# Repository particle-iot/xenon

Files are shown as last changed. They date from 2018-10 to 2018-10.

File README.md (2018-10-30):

# Xenon

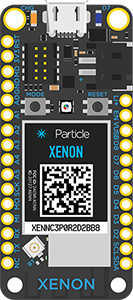
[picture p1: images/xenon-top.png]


### Overview

The Xenon is a low cost mesh-enabled development board that can act as either an endpoint or repeater within a Particle Mesh network.

The Xenon is mesh only and designed to function as the endpoint of your IoT network. It is based on the Nordic nRF52840 and has built-in battery charging circuitry so it’s easy to connect a Li-Po and deploy your local network in minutes.

The Xenon is best for connecting sensors, motors, pumps, valves, and points of data-interest. Pair it with an Argon or Boron gateway to get all that great data into the Device Cloud.

### Features

* Nordic Semiconductor nRF52840 SoC 
  * ARM Cortex-M4F 32-bit processor @ 64MHz 
  * 1MB flash, 256KB RAM 
  * IEEE 802.15.4-2006: 250 Kbps 
  * Bluetooth 5: 2 Mbps, 1 Mbps, 500 Kbps, 125 Kbps 
  * Supports DSP instructions, HW accelerated Floating Point Unit (FPU) calculations 
  * ARM TrustZone CryptoCell-310 Cryptographic and security module 
  * Up to +8 dBm TX power (down to -20 dBm in 4 dB steps) 
  * NFC-A tag
* On-board additional 2MB SPI flash
* 20 mixed signal GPIO (6 x Analog, 8 x PWM), UART, I2C, SPI
* Micro USB 2.0 full speed (12 Mbps)
* Integrated Li-Po charging and battery connector
* JTAG (SWD) Connector
* RGB status LED
* Reset and Mode buttons
* On-board PCB antenna
* u.FL connector for external antenna
* Meets the Adafruit Feather [specification](https://learn.adafruit.com/adafruit-feather/feather-specification) in dimensions and pinout
* FCC, CE and IC certified
* RoHS compliant (lead-free)

### Structure of this repository:
 - /eagle
     + Contains the schematic and PCB files in the Eagle file format
 - /gerbers
     + Contains the manufacturing gerber files for the board
 - /datasheets
     + Contains the relevant datasheets of the components used on the Xenon
 - /pdfs
     + Contains schematic files in PDF 

### Hardware datasheet

The complete datasheet for the Xenon is available [here.](https://docs.particle.io/datasheets/mesh/xenon-datasheet/)

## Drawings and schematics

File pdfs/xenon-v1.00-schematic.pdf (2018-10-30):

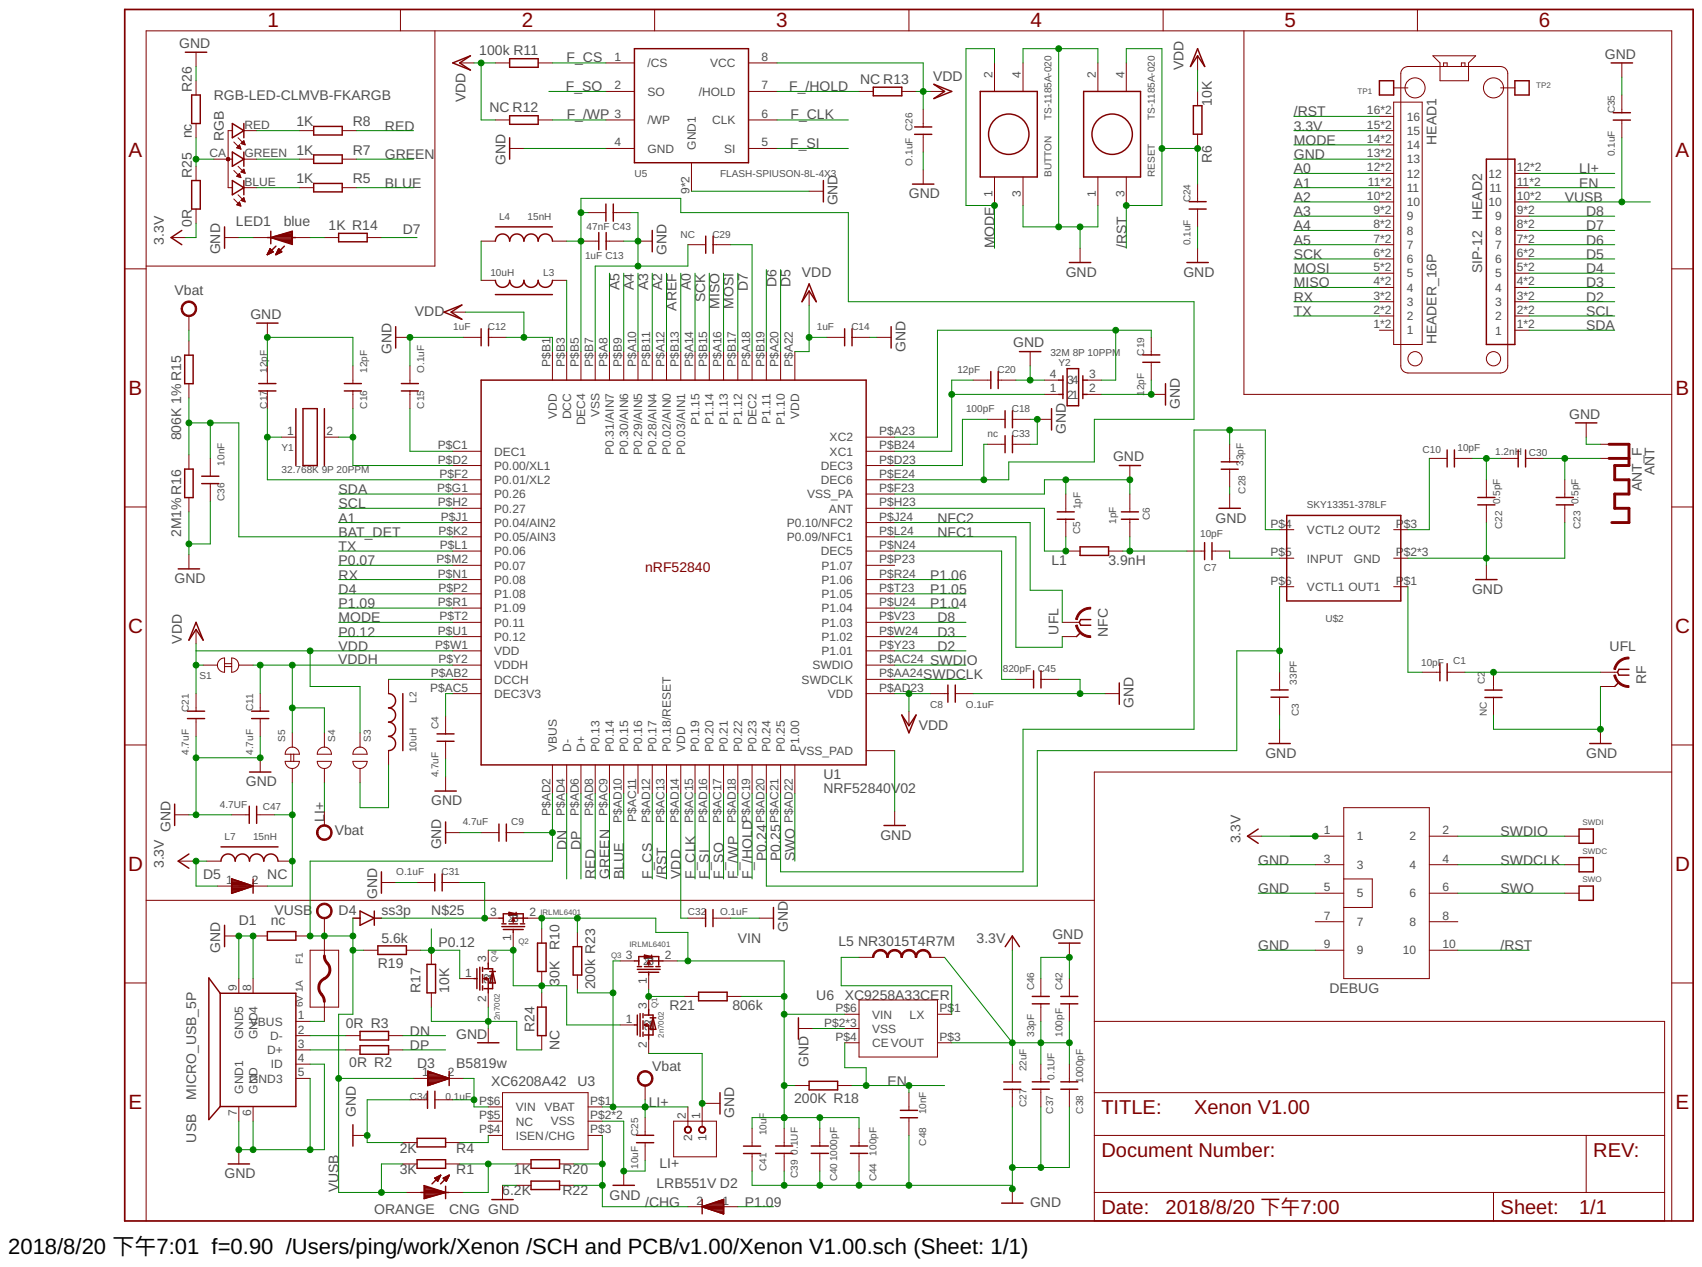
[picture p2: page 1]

RGB-LED-CLMVB-FKARGB
BLUE CARGB
RED GREEN

Document Number: | REV:

Date: 2018/8/20 下午7:00 | Sheet: 1/1

2018/8/20 下午7:01 f=0.90 /Users/ping/work/Xenon /SCH and PCB/v1.00/Xenon V1.00.sch (Sheet: 1/1)

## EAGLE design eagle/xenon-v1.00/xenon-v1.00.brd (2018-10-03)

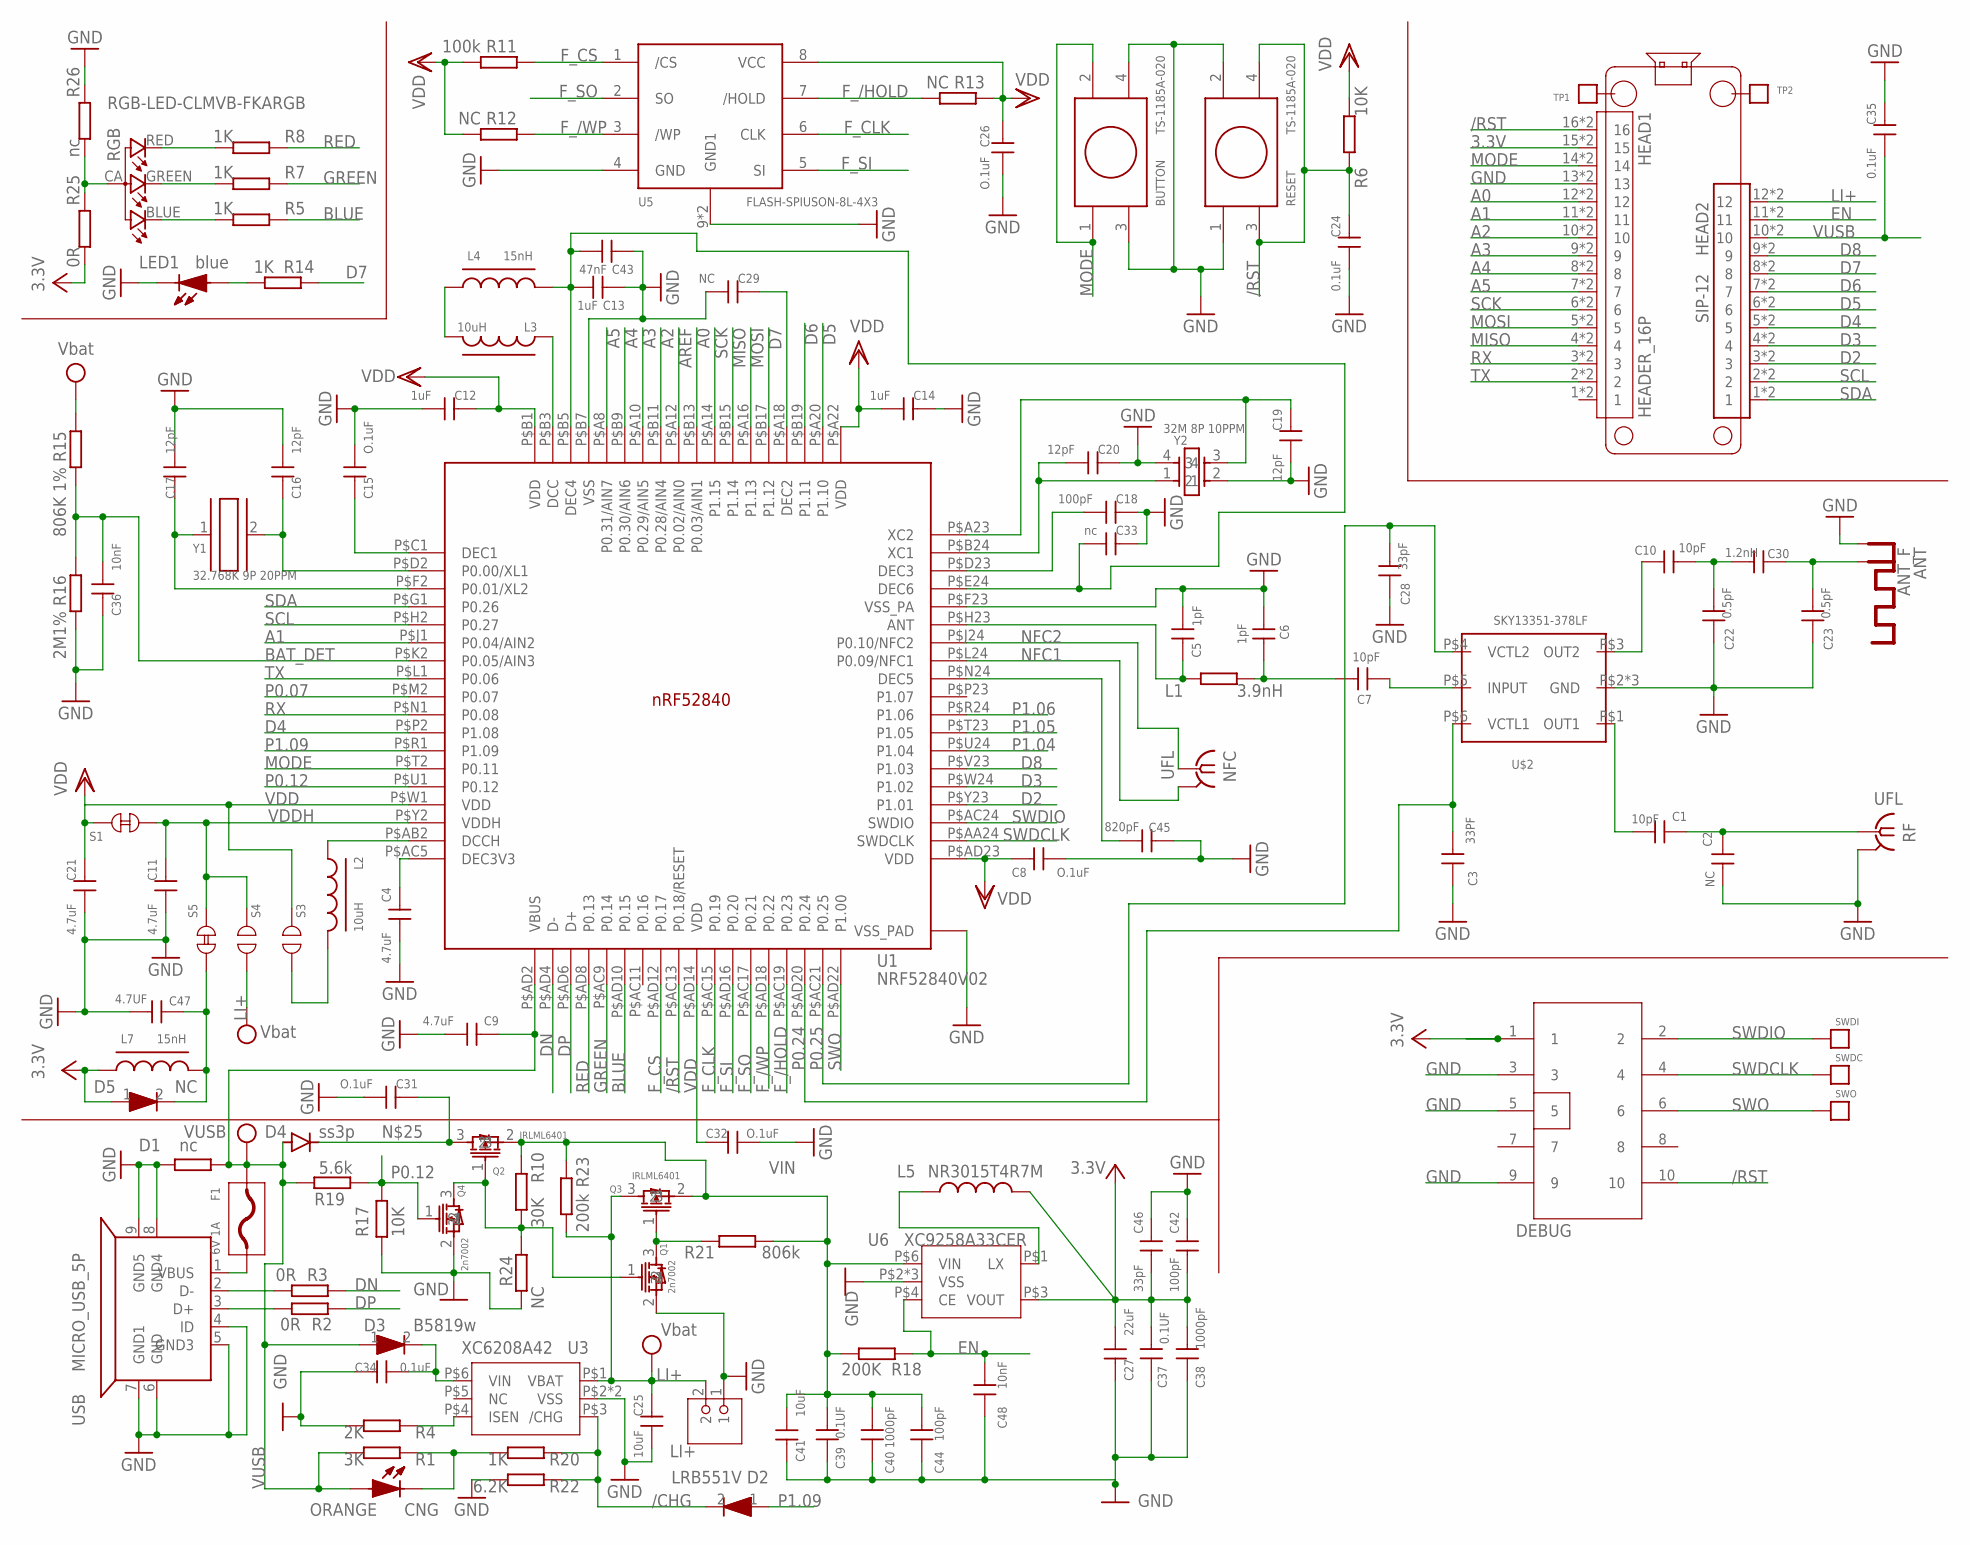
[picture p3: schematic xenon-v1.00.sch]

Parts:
ANT: ANT_F; ANTENNA_F2_PCB
BAT: CON2P_SMT; CON_2.0MM_SMT
BUTTON: TS-1185A-020
C1, C7, C10: 10pF; C-0402
C2, C29: NC; C-0402
C3: 33PF; C-0402
C4, C9, C11, C21: 4.7uF; C-0402
C5, C6: 1pF; C-0402
C8, C15, C26, C31, C32: O.1uF; C-0402
C12, C13, C14: 1uF; C-0402
C16, C17, C19, C20: 12pF; C-0402
C18, C42, C44: 100pF; C-0402
C22, C23: 0.5pF; C-0402
C24, C34, C35: 0.1uF; C-0402
C25: 10uF; C0805
C27: 22uF; C0805
C28, C46: 33pF; C-0402
C30: 1.2nH; C-0402
C33: nc; C-0402
C36, C48: 10nF; C-0402
C37, C39: 0.1UF; C-0402
C38, C40: 1000pF; C-0402
C41: 10uF; C0603
C43: 47nF; C-0402
C45: 820pF; C-0402
C47: 4.7UF; C-0402
CNG: ORANGE; LED0603
D1: nc; R-0402S
D2: LRB551V; SOD-323
D3: B5819w; SOD-123
D4: ss3p; DIODE-DO-220AA(SMP)
D5: NC; SOD-323
DEBUG: CON5X2; CON5X2_1.27
F1: 6V 1A; F0805
HEAD1: HEADER_16P; HEADER_16P2.54
HEAD2: SIP-12
L1: 3.9nH; R-0402S
L2, L3: 10uH; R-0603A
L4, L7: 15nH; R-0402S
L5: NR3015T4R7M; INDUCTOR-NR3015
LED1: blue; LED0603
NFC: UFL; IPEX-20279-001E
Q1, Q4: 2n7002; SOT323
Q2, Q3: IRLML6401; SOT-23
R1: 3K; R-0402S
R2, R3, R25: 0R; R-0402S
R4: 2K; R-0402S
R5, R7, R8, R14, R20: 1K; R-0402S
R6, R17: 10K; R-0402S
R10: 30K; R-0402S
R11: 100k; R-0402S
R12, R13, R24: NC; R-0402S
R15: 806K 1%; R-0402S
R16: 2M1%; R-0402S
R18: 200K; R-0402S
R19: 5.6k; R-0402S
R21: 806k; R-0402S
R22: 6.2K; R-0402S
R23: 200k; R-0402S
R26: nc; R-0402S
RESET: TS-1185A-020
RF: UFL; IPEX-20279-001E
RGB: RGB-LED-CLMVB-FKARGB; PLCC4-2MM-RGB
S1, S5: TP_SHORT
S3, S4: TP_OPEN
SWDC: TPTP; TP
SWDI: TPTP; TP
SWO: TPTP; TP
TP1, TP2: TPTP2.5; TP-2.5
U1: NRF52840V02; AQN507X7X0.85_HA-74_V2
U3: XC6208A42; USP-6C
U5: FLASH-SPIUSON-8L-4X3; USON8-3X4
U6: XC9258A33CER; USP-6C
U$2: SKY13351-378LF; MLPD-6-1X1
USB: MICRO_USB_5P; MICRO_USB
Y1: 32.768K 9P 20PPM; CRY_3215
Y2: 32M 8P 10PPM; CRY_2520

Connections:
3.3V: C27.1, C37.2, C38.2, C42.2, C46.2, D5.1, DEBUG.1, HEAD1.15, HEAD1.P$15 (15), L5.2, L7.1, R25.2, U6.P$3 (VOUT)
/CHG: D2.2, R20.1, R22.1, U3.P$3 (/CHG)
/RST: C24.2, DEBUG.10, HEAD1.16, HEAD1.P$16 (16), R6.1, RESET.3, RESET.4, U1.P$AC13 (P0.18/RESET)
A0: HEAD1.12, HEAD1.P$12 (12), U1.P$B13 (P0.03/AIN1)
A1: HEAD1.11, HEAD1.P$11 (11), U1.P$J1 (P0.04/AIN2)
A2: HEAD1.10, HEAD1.P$10 (10), U1.P$B11 (P0.28/AIN4)
A3: HEAD1.9, HEAD1.P$9 (9), U1.P$A10 (P0.29/AIN5)
A4: HEAD1.8, HEAD1.P$8 (8), U1.P$B9 (P0.30/AIN6)
A5: HEAD1.7, HEAD1.P$7 (7), U1.P$A8 (P0.31/AIN7)
AREF: U1.P$A12 (P0.02/AIN0)
BAT_DET: C36.1, R15.2, R16.1, U1.P$K2 (P0.05/AIN3)
BLUE: R5.1, U1.P$AD10 (P0.15)
D2: HEAD2.3, HEAD2.P$3 (3), U1.P$Y23 (P1.01)
D3: HEAD2.4, HEAD2.P$4 (4), U1.P$W24 (P1.02)
D4: HEAD2.5, HEAD2.P$5 (5), U1.P$P2 (P1.08)
D5: HEAD2.6, HEAD2.P$6 (6), U1.P$A20 (P1.10)
D6: HEAD2.7, HEAD2.P$7 (7), U1.P$B19 (P1.11)
D7: HEAD2.8, HEAD2.P$8 (8), R14.1, U1.P$B17 (P1.12)
D8: HEAD2.9, HEAD2.P$9 (9), U1.P$V23 (P1.03)
D+: R2.2, USB.3 (D+)
D-: R3.2, USB.2 (D-)
DN: R3.1, U1.P$AD4 (D-)
DP: R2.1, U1.P$AD6 (D+)
EN: C48.2, HEAD2.11, HEAD2.P$11 (11), R18.1, U6.P$4 (CE)
F_/HOLD: R13.2, U1.P$AC19 (P0.23), U5.7 (/HOLD)
F_/WP: R12.1, U1.P$AD18 (P0.22), U5.3 (/WP)
F_CLK: U1.P$AC15 (P0.19), U5.6 (CLK)
F_CS: R11.1, U1.P$AD12 (P0.17), U5.1 (/CS)
F_SI: U1.P$AD16 (P0.20), U5.5 (SI)
F_SO: U1.P$AC17 (P0.21), U5.2 (SO)
GND: ANT.GND, BAT.1, BUTTON.3, BUTTON.4, C2.2, C3.1, C4.1, C5.1, C6.1, C8.1, C9.1, C11.1, C12.1, C13.2, C14.2, C15.1, C16.1, C17.1, C18.2, C19.1, C20.2, C21.1, C22.1, C23.1, C24.1, C25.1, C26.1, C27.2, C28.1, C29.1, C31.1, C32.1, C33.2, C34.2, C35.2, C36.2, C37.1, C38.1, C39.1, C40.1, C41.2, C42.1, C43.2, C44.1, C45.2, C46.1, C47.2, C48.1, D1.1, DEBUG.3, DEBUG.5, DEBUG.9, HEAD1.13, HEAD1.P$13 (13), LED1.2 (K), Q1.2, Q4.2, R4.2, R16.2, R17.1, R22.2, R24.1, R26.1, RESET.1, RESET.2, RF.2@1 (GND), RF.2@2 (GND), U1.P$74 (VSS_PAD), U1.P$75 (VSS_PAD), U1.P$76 (VSS_PAD), U1.P$77 (VSS_PAD), U1.P$78 (VSS_PAD), U1.P$79 (VSS_PAD), U1.P$80 (VSS_PAD), U1.P$81 (VSS_PAD), U1.P$82 (VSS_PAD), U1.P$85 (VSS_PAD), U1.P$B7 (VSS), U1.P$F23 (VSS_PA), U3.P$2 (VSS), U3.P$7 (VSS), U5.4 (GND), U5.9 (GND1), U5.10 (GND1), U6.P$2 (VSS), U6.P$5 (VSS), U6.P$7 (VSS), U$2.P$2 (GND), U$2.P$7 (GND), U$2.P$8 (GND), USB.4 (ID), USB.5 (GND3), USB.6 (GND), USB.7 (GND1), USB.8 (GND4), USB.9 (GND5), Y2.2, Y2.4
GREEN: R7.1, U1.P$AC9 (P0.14)
LI+: BAT.2, C25.2, HEAD2.12, HEAD2.P$12 (12), Q3.3, R15.1, R23.1, S4.1, U3.P$1 (VBAT)
MISO: HEAD1.4, HEAD1.P$4 (4), U1.P$B15 (P1.14)
MODE: BUTTON.1, BUTTON.2, HEAD1.14, HEAD1.P$14 (14), U1.P$T2 (P0.11)
MOSI: HEAD1.5, HEAD1.P$5 (5), U1.P$A16 (P1.13)
unnamed: L2.1, U1.P$AB2 (DCCH)
unnamed: C5.2, L1.1, U1.P$H23 (ANT)
unnamed: C6.2, C7.2, L1.2
unnamed: C16.2, U1.P$D2 (P0.00/XL1), Y1.2
unnamed: C13.1, C33.1, C43.1, L4.2, U1.P$B5 (DEC4), U1.P$E24 (DEC6)
unnamed: L3.2, L4.1
unnamed: L3.1, U1.P$B3 (DCC)
unnamed: C15.2, U1.P$C1 (DEC1)
unnamed: C17.2, U1.P$F2 (P0.01/XL2), Y1.1
unnamed: C1.1, C2.1, RF.1
unnamed: C19.2, U1.P$A23 (XC2), Y2.3
unnamed: C18.1, U1.P$D23 (DEC3)
unnamed: LED1.1 (A), R14.2
unnamed: L2.2, S3.1
unnamed: C20.1, U1.P$B24 (XC1), Y2.1
unnamed: C7.1, U$2.P$5 (INPUT)
unnamed: C10.1, U$2.P$3 (OUT2)
unnamed: F1.P$1 (1), USB.1 (VBUS)
unnamed: C47.1, D5.2, L7.2, S5.2
unnamed: CNG.2 (K), R1.1, R20.2
unnamed: R4.1, U3.P$4 (ISEN)
unnamed: R8.2, RGB.RED (4)
unnamed: R25.1, R26.2, RGB.CA (1)
unnamed: C31.2, D4.CATHODE, Q2.3
unnamed: R5.2, RGB.BLUE (2)
unnamed: R7.2, RGB.GREEN (3)
unnamed: C29.2, U1.P$A18 (DEC2)
unnamed: C4.2, U1.P$AC5 (DEC3V3)
unnamed: C45.1, U1.P$N24 (DEC5)
unnamed: C10.2, C22.2, C30.2
unnamed: ANT.RF, C23.2, C30.1
unnamed: Q1.1, Q2.1, Q4.3, R10.1, R24.2
unnamed: C1.2, U$2.P$1 (OUT1)
unnamed: C34.1, D3.2, U3.P$6 (VIN)
unnamed: Q1.3, Q3.1, R21.2
unnamed: L5.1, U6.P$1 (LX)
NFC1: NFC.2@1 (GND), NFC.2@2 (GND), U1.P$L24 (P0.09/NFC1)
NFC2: NFC.1, U1.P$J24 (P0.10/NFC2)
P0.07: U1.P$M2 (P0.07)
P0.12: Q4.1, R17.2, R19.2, U1.P$U1 (P0.12)
P0.24: C3.2, U1.P$AD20 (P0.24), U$2.P$6 (VCTL1)
P0.25: C28.2, U1.P$AC21 (P0.25), U$2.P$4 (VCTL2)
P1.04: U1.P$U24 (P1.04)
P1.05: U1.P$T23 (P1.05)
P1.06: U1.P$R24 (P1.06)
P1.09: D2.1, U1.P$R1 (P1.09)
RED: R8.1, U1.P$AD8 (P0.13)
RX: HEAD1.3, HEAD1.P$3 (3), U1.P$N1 (P0.08)
SCK: HEAD1.6, HEAD1.P$6 (6), U1.P$A14 (P1.15)
SCL: HEAD2.2, HEAD2.P$2 (2), U1.P$H2 (P0.27)
SDA: HEAD2.1, HEAD2.P$1 (1), U1.P$G1 (P0.26)
SWDCLK: DEBUG.4, SWDC.P$1, U1.P$AA24 (SWDCLK)
SWDIO: DEBUG.2, SWDI.P$1, U1.P$AC24 (SWDIO)
SWO: DEBUG.6, SWO.P$1, U1.P$AD22 (P1.00)
TX: HEAD1.2, HEAD1.P$2 (2), U1.P$L1 (P0.06)
VDD: C8.2, C12.2, C14.1, C21.2, C26.2, C32.2, R6.2, R11.2, R12.2, R13.1, S1.1, S3.2, U1.P$A22 (VDD), U1.P$AD14 (VDD), U1.P$AD23 (VDD), U1.P$B1 (VDD), U1.P$W1 (VDD), U5.8 (VCC)
VDDH: C11.2, S1.2, S4.2, S5.1, U1.P$Y2 (VDDH)
VIN: C39.2, C40.2, C41.1, C44.2, Q2.2, Q3.2, R10.2, R18.2, R21.1, R23.2, U6.P$6 (VIN)
VUSB: C9.2, C35.1, CNG.1 (A), D1.2, D3.1, D4.ANODE, F1.P$2 (2), HEAD2.10, HEAD2.P$10 (10), R1.2, R19.1, U1.P$AD2 (VBUS)

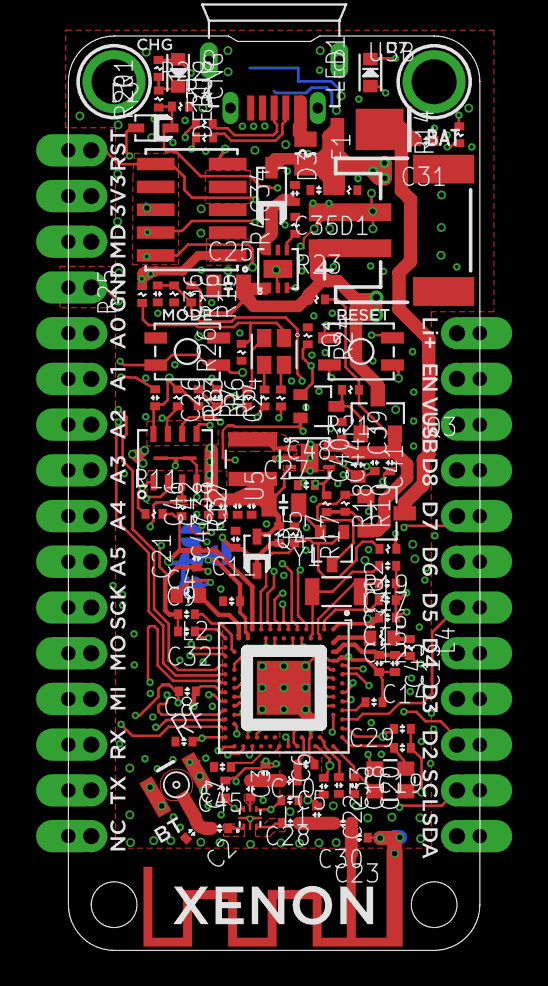
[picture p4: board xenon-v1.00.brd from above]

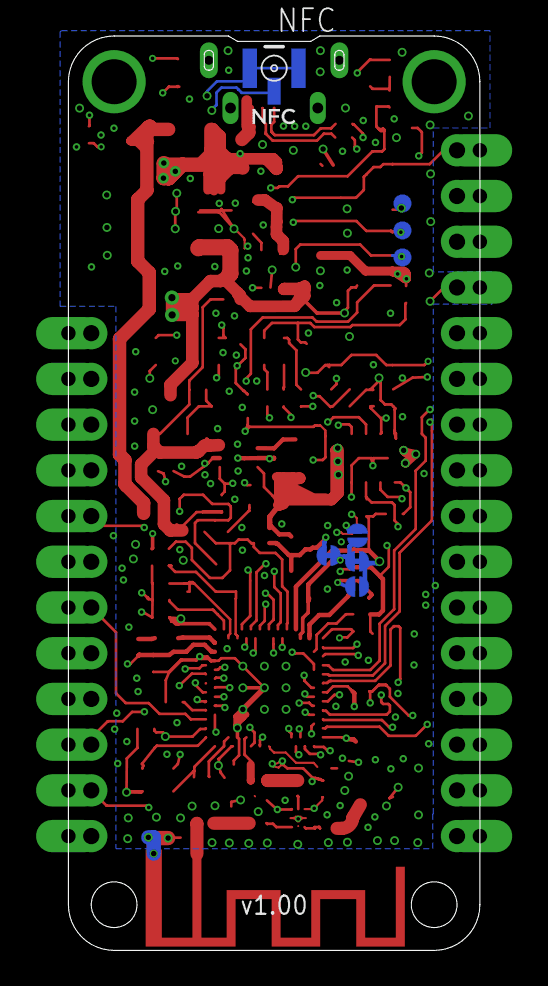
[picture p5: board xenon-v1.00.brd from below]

Board: 4 copper layers, 22.9 x 50.8 mm, 118 parts (8 on the bottom side), 90 nets.

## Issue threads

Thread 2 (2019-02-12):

wrong datasheet for spi nor flash?

pabigot, 2019-02-12:
The datasheets directory has a datasheet for the MX25L1606E, which was presumably the originally-planned 16 Mibit flash.  The 32 Mibit flash datasheet is for the GigaDevice GD25Q32C.  However, that device has a JEDEC id of 0xc84016.

The device in my Xenon has a JEDEC id of 0xc22016, which is a Macronix MX25L3205D.

The two devices are fairly close, but the GigaDevice promises significantly lower standby and deep power-down current consumption than Macronix.  Identifying the correct device explains some of the differences I'd noticed.

pabigot, 2019-02-12:
Actually, it's more likely it's the MX25L3206E, which has the same JEDEC ID but supports QSPI and is only NRND rather than EOL.

pabigot, 2019-02-13:
Nope.  It's actually the MX25L3233F, based on the contents of the SFDP.

rickkas7, 2019-03-04:
You are correct. It is the MX25L3233F and I removed the incorrect ones and added that one to the datasheets directory.

Closed 2019-03-04.

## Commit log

2018-10-03 added design files
    [xenon-v1.00.brd, xenon-v1.00.sch]
2019-03-04 Include MX25L3233F SPI flash datasheet
